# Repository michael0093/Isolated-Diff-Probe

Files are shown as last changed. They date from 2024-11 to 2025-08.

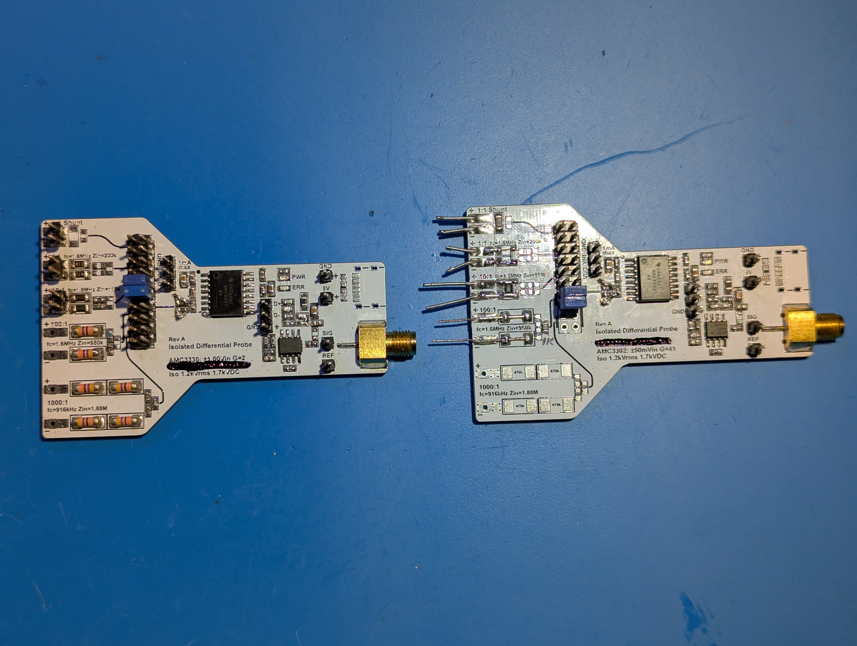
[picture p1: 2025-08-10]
Assembled front with rev A2 mods.jpg

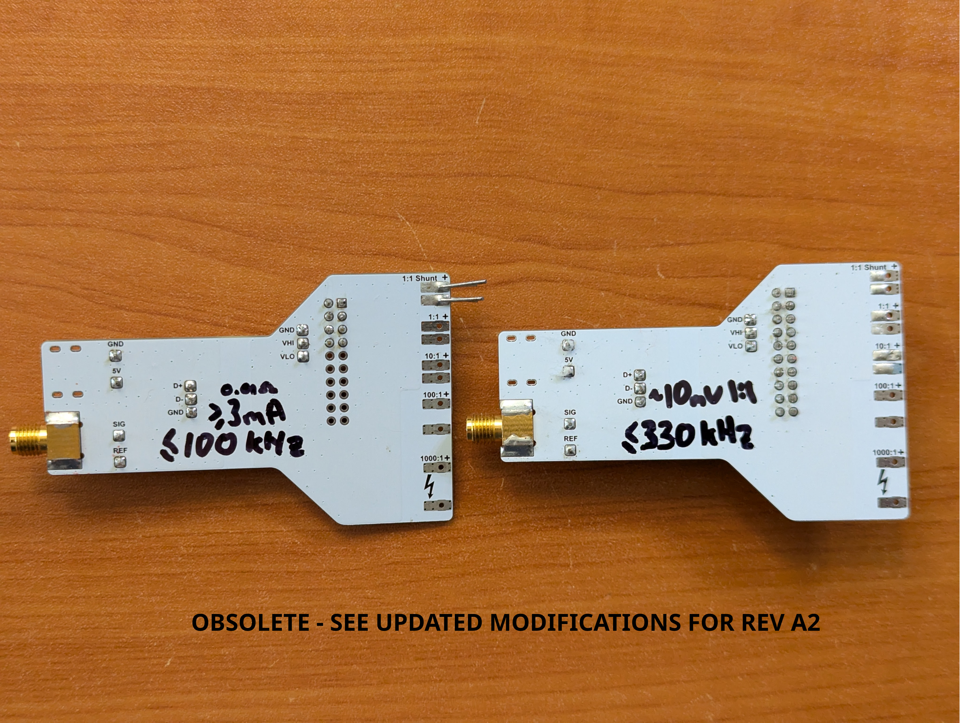
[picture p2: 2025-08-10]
Assembled back rev A1 mods.jpg

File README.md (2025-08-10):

# Overview
The Ti AMC33xx are differential isolated analog amplifiers rated for minimum 1.2kVrms insulation. The AMC3302 is intended for current shunt inputs as it has a +/-50mVpp input with a fixed gain of 41, whereas the AMC3330 is better for voltage measurements as it has a +/-1Vpp input and a fixed gain of 2. In these probes the AMC33xx do all the work, with their differential output converted to single-ended by a dual op-amp to better suit most oscilloscopes. 
By using two 2.54" jumpers on the 2x10 header, you can select between various input attenuators for low to high voltage use. 

# Design Notes
The power supply must be isolated from your scope as the scope "GND" of the SMA connector is a 50%VDD bias voltage. 
The schematic has two modifications from the rev A to rev A2 design - refer to the rev B schematic and follow the notes. The modifications are:
- Two biasing 1M (AMC3300) or 100k (AMC3302) resistors from near the input selector to HGND
- Two filtering 33pF (AMC3300) or 3.3nF (AMC3302) capacitors from near the input selector to HGND
- General note: The PCB is marked with an fc of the input circuit, not of the complete probe. The fc of the complete probe is about 300kHz.

The design was originally done in Altium and then converted to KiCad so appologies that the KiCad sch/pcb may not link up quite right. For that reason there are no propper rev B output files, and also note the rev B PCB still has outstanding changes as noted on the schematic.

Other opamps with GBWP >1MHz or so should perform similarly, the OPA2376 is just what was on hand.
Based on practical usage, the AMC3302 with a 0R01 shunt works best for currents >=3mA with fc=100kHz. The AMC3330 on 1:1 range works best for voltages >=10mV and fc=300kHz.

# Disclaimer
Only use the high voltage inputs if you are suitably qualified to measure lethal voltages and completely understand the risks. This project is provided as reference material only and anyone who attempts to make it must fully understand the risks and limitations of the isolator used - this project has absolutely no warranty and may be completely unsuitable for your use case. Use completely at your own risk!

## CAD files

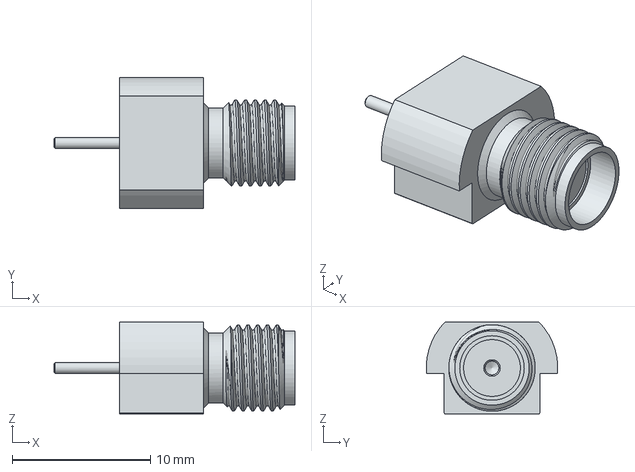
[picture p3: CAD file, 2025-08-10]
KiCad rev B/ALTIUM_EMBEDDED_MODELS/Cinch 142-0721-881.stp
17.4 x 9.52 x 6.65 mm

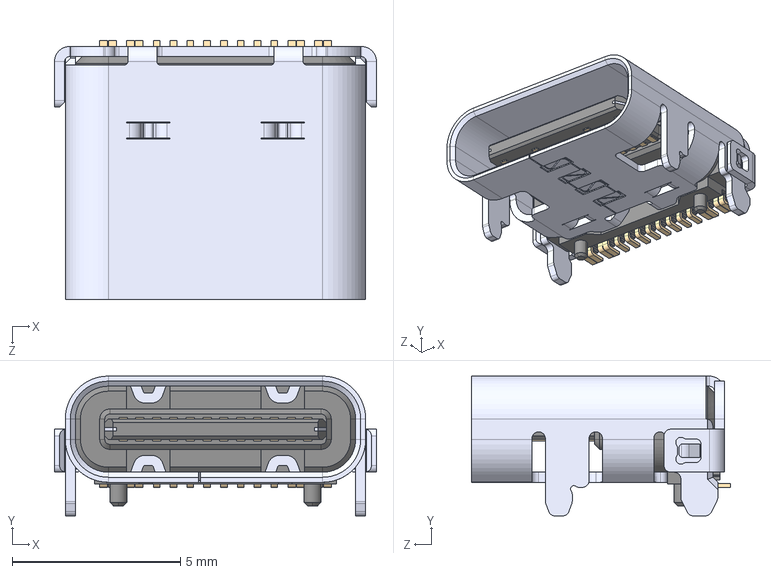
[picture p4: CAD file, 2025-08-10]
KiCad rev B/ALTIUM_EMBEDDED_MODELS/USB4105-GF-A--3DModel-STEP-46669.STEP
9.58 x 4.16 x 7.71 mm

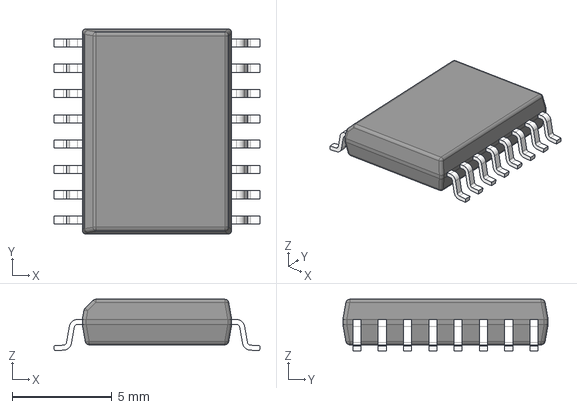
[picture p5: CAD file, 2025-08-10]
KiCad rev B/ALTIUM_EMBEDDED_MODELS/DW0016B.stp
10.3 x 10.3 x 2.59 mm
BODY-SOIC
LEAD-DW0016 x 16

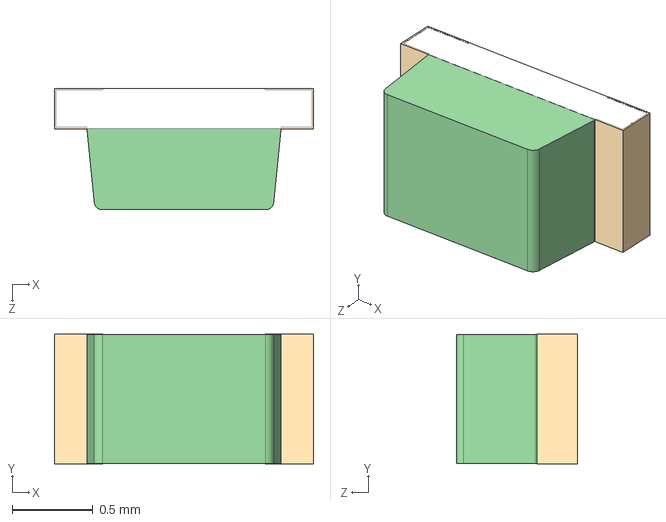
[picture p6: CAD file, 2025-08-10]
KiCad rev B/ALTIUM_EMBEDDED_MODELS/LED 0603 APT1608 GREEN.STEP
1.60 x 0.8 x 0.75 mm

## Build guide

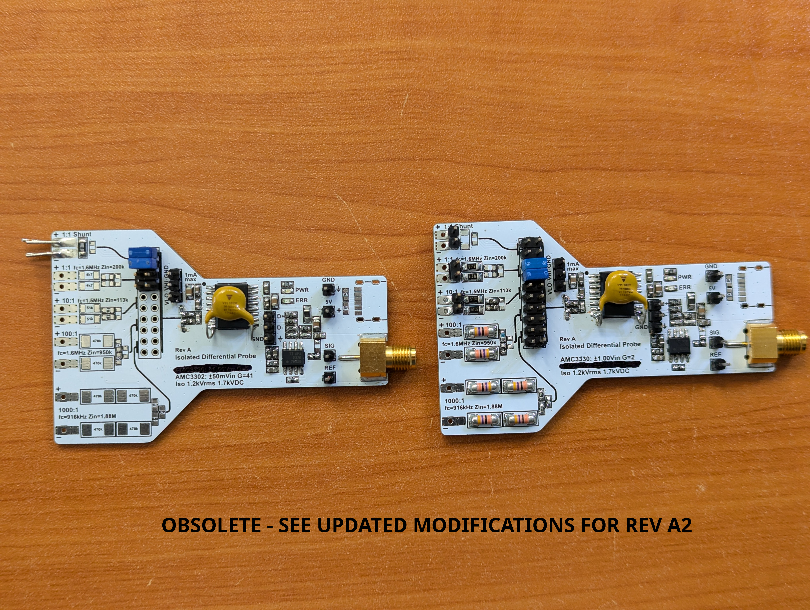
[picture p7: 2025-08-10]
Assembled front rev A1 mods.jpg

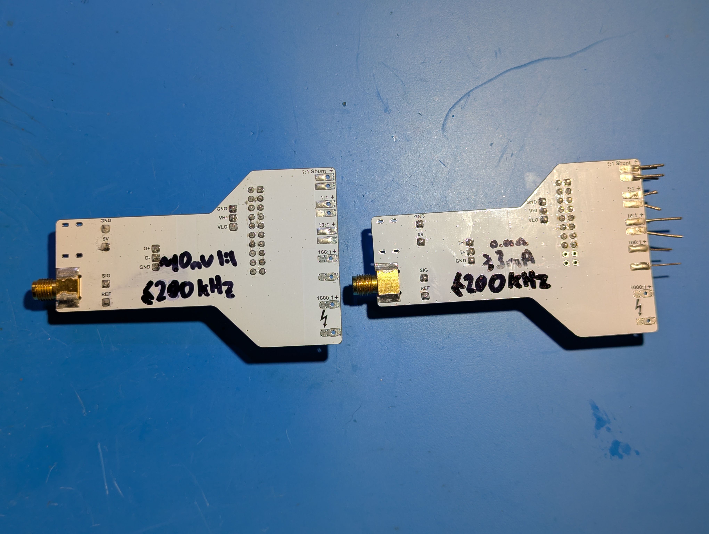
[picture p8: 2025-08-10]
Assembled back with rev A2 mods.jpg

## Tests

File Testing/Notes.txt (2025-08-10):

Changes to the rev A PCB to make rev A1:
 * 1nF Y1 capacitor between isolated GNDs avoids some weird noise 'glitches' at higher frequencies mainly on the AMC3302 (other values probably fine)
 * 1M bias resistors from each input to GND avoid clipping of tops of sine, probably due to bias
 * Adding 47uF HXD at input or output caps didn't help.
 * Opamp resistors change from 10k to 4k7 and the capacitors from 1nF to 100pF to increase frequency response
 * Actual opamp is OPA2376 (thats what was on hand)
 
At 5V input, typ current draw is 30mA

Shunt diff probe AMC3302:
 Fitted with 0R01 shunt LRMAM1206-R01FT5 (Element14 # 207-9442)
 Minimum recommended current with 10mR shunt = 3mA which results in about 1.2mV at output.
 Measured 3dB point (100mA on 0R01 shunt) = 220 kHz but see note below
 At higher freq the noise beats with the measurement so you get weirdness (note: adding 47uF or bigger Y1 doesnt help)
 Noise at output with shorted input much worse so dont do that (?)
 
Voltage diff probe AMC3330:
 470K on physical sample is the Resistor Today part
 Measured 3dB point (1Vpp input) = 330kHz
 The weirdness noted for AMC3302 is also present for AMC3330 if you have a small signal
    -- this root cause has been solved in rev B1 see below.

*******************************
Updates for Rev B August 2025: All of these except the diode and 1k shunt input resistors have been applied as mods for the rev A2 design

 * Change C12 and C15 to 33pF to improve frequency response
 * Updated input filter and bias, adding capacitance to HGND is what solves the "weirdness" observed before and negates the need for the Y1 cap. The Y1 cap is detremental to the higher voltage input options (waveform distortion)
   * For AMC3300 voltage probe, input filter/bias is: R34.R33=1M. C11,C20,C21=33pF. Added R35,R36 to reduce freq of shunt input (else >>1M target)
   * For AMC3302 current probe, input filter/bias is: R34.R33=100k. C11,C20,C21=3.3nF
 * Added anti-parallel diode at power input for crude polarity protection
 * For AMC3300 with shunt, added series R35,R36=1k and C1=100nF to reduce fc

Rev B1 AMC3302 measured frequency response with sine:
With 100pF in opamp circuit:
    large signal on 1R shunt:   4.76V at 1kHz --> 3.36V at 210kHz
    small signal on 0R01 shunt: 388mV at 1kHz --> 274mV at 230kHz
After changing to 33pF in opamp circuit: 1R shunt is about 280kHz -- see charts in folder.

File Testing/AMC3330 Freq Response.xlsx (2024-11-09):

Time | Milliseconds | Index | Freq | Vin | Vout | dB | Phase | Point of: | -3 | dB
2024-11-09 15:15 | 2008 | 0 | 100 | 0.3561504 | 0.347695 | -0.2086998211 | 1.8 | Is at: | 233957.04 | Hz
2024-11-09 15:15 | 3181 | 1 | 105 | 0.3493349 | 0.3419792 | -0.1848456719 | 1.875
2024-11-09 15:15 | 4342 | 2 | 110.25 | 0.3558902 | 0.3554921 | -0.009721504248 | 6
2024-11-09 15:15 | 5461 | 3 | 115.76 | 0.3554602 | 0.347701 | -0.1917008235 | 2.093023
2024-11-09 15:15 | 6561 | 4 | 121.55 | 0.3491731 | 0.341468 | -0.1938153554 | 2.195122
2024-11-09 15:15 | 7640 | 5 | 127.63 | 0.3544487 | 0.3550352 | 0.01436051032 | 6.923077
2024-11-09 15:15 | 8701 | 6 | 134.01 | 0.3522641 | 0.3451684 | -0.1767471226 | 2.432432
2024-11-09 15:16 | 9750 | 7 | 140.71 | 0.3498141 | 0.3427191 | -0.1779800397 | 7.605634
2024-11-09 15:16 | 10780 | 8 | 147.75 | 0.3535281 | 0.3467842 | -0.1672927404 | 2.647059
2024-11-09 15:16 | 11791 | 9 | 155.14 | 0.3481743 | 0.3412272 | -0.1750613728 | 2.8125
2024-11-09 15:16 | 12800 | 10 | 162.9 | 0.354125 | 0.3548377 | 0.01746336057 | 2.950819
2024-11-09 15:16 | 13782 | 11 | 171.05 | 0.3476241 | 0.3415127 | -0.1540603769 | 3.103448
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

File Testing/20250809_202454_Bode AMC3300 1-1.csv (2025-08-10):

Time | Milliseconds | Index | Freq | Vin | Vout | dB | Phase
2025-08-09 20:24:55.998415 | 1487 | 0 | 100 | 0.7121296 | 1.409242 | 5.928530805867616 | 1.8
2025-08-09 20:24:57.458087 | 2947 | 1 | 105.0 | 0.7028115 | 1.388614 | 5.914853606404074 | 1.894737
2025-08-09 20:24:58.895924 | 4385 | 2 | 110.25 | 0.7153466 | 1.41075 | 5.898670832471245 | 1.978022
2025-08-09 20:25:00.313034 | 5802 | 3 | 115.76 | 0.7137467 | 1.40952 | 5.910542585035337 | 2.068965
2025-08-09 20:25:01.726092 | 7215 | 4 | 121.55 | 0.7015346 | 1.384577 | 5.905360350617944 | 2.195122
2025-08-09 20:25:03.105063 | 8594 | 5 | 127.63 | 0.7138692 | 1.405347 | 5.883298525158161 | 2.278481
2025-08-09 20:25:04.465987 | 9955 | 6 | 134.01 | 0.7066419 | 1.394556 | 5.90473146793423 | 2.4
2025-08-09 20:25:05.809647 | 11299 | 7 | 140.71 | 0.7031512 | 1.38707 | 5.900993130069296 | 2.535211
2025-08-09 20:25:07.137218 | 12626 | 8 | 147.75 | 0.711116 | 1.402429 | 5.89880866777023 | 2.686567
2025-08-09 20:25:08.449217 | 13938 | 9 | 155.14 | 0.6994988 | 1.378212 | 5.890581063560397 | 2.8125
2025-08-09 20:25:09.754534 | 15244 | 10 | 162.9 | 0.7101219 | 1.399283 | 5.891453029734988 | 2.903226
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

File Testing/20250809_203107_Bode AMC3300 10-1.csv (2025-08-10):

Time | Milliseconds | Index | Freq | Vin | Vout | dB | Phase
2025-08-09 20:31:08.877084 | 1482 | 0 | 100 | 7.225853 | 1.401103 | -14.248381184582994 | -1.8
2025-08-09 20:31:10.336949 | 2942 | 1 | 105.0 | 7.123918 | 1.377365 | -14.27339737724514 | -1.894737
2025-08-09 20:31:11.780669 | 4386 | 2 | 110.25 | 7.259896 | 1.404466 | -14.26838338611185 | -1.978022
2025-08-09 20:31:13.198005 | 5803 | 3 | 115.76 | 7.244632 | 1.39961 | -14.280185861097717 | -2.093023
2025-08-09 20:31:14.595421 | 7200 | 4 | 121.55 | 7.123964 | 1.375184 | -14.287218107431585 | -2.195122
2025-08-09 20:31:15.975531 | 8581 | 5 | 127.63 | 7.249256 | 1.39523 | -14.312952617385342 | -2.307692
2025-08-09 20:31:17.336164 | 9941 | 6 | 134.01 | 7.176553 | 1.383823 | -14.296707039252043 | -2.4
2025-08-09 20:31:18.679773 | 11285 | 7 | 140.71 | 7.13756 | 1.375945 | -14.29897395304401 | -2.535211
2025-08-09 20:31:20.006949 | 12612 | 8 | 147.75 | 7.227983 | 1.392387 | -14.305143251901676 | -2.647059
2025-08-09 20:31:21.318870 | 13924 | 9 | 155.14 | 7.093113 | 1.364958 | -14.31435180723038 | -2.8125
2025-08-09 20:31:22.616050 | 15221 | 10 | 162.9 | 7.202491 | 1.389629 | -14.291677109993259 | -2.903226
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

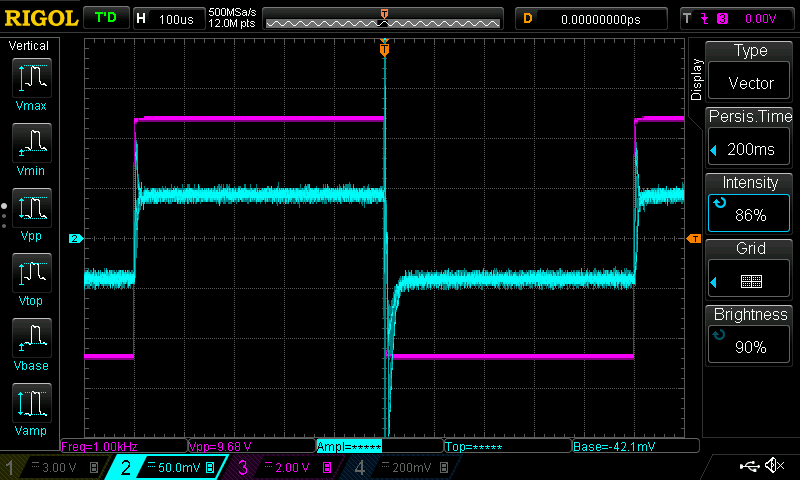
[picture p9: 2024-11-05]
Testing/AMC3302 100mA on 0R01 Square 1.png

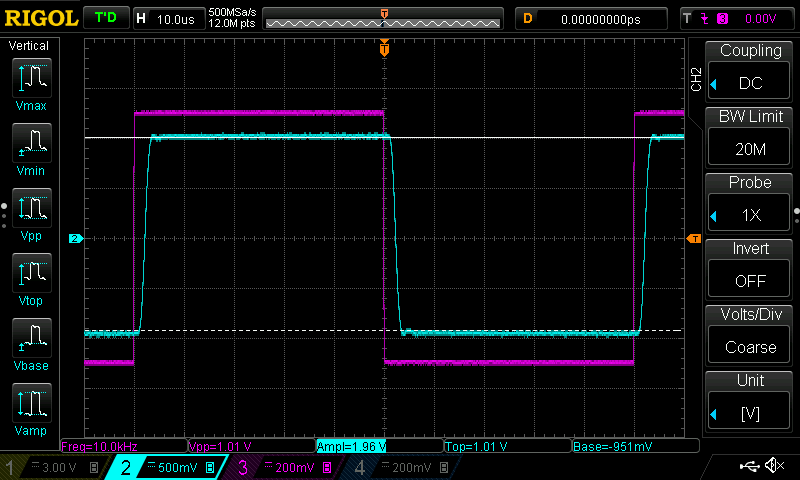
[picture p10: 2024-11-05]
Testing/AMC3330 1V 10kHz Square.png

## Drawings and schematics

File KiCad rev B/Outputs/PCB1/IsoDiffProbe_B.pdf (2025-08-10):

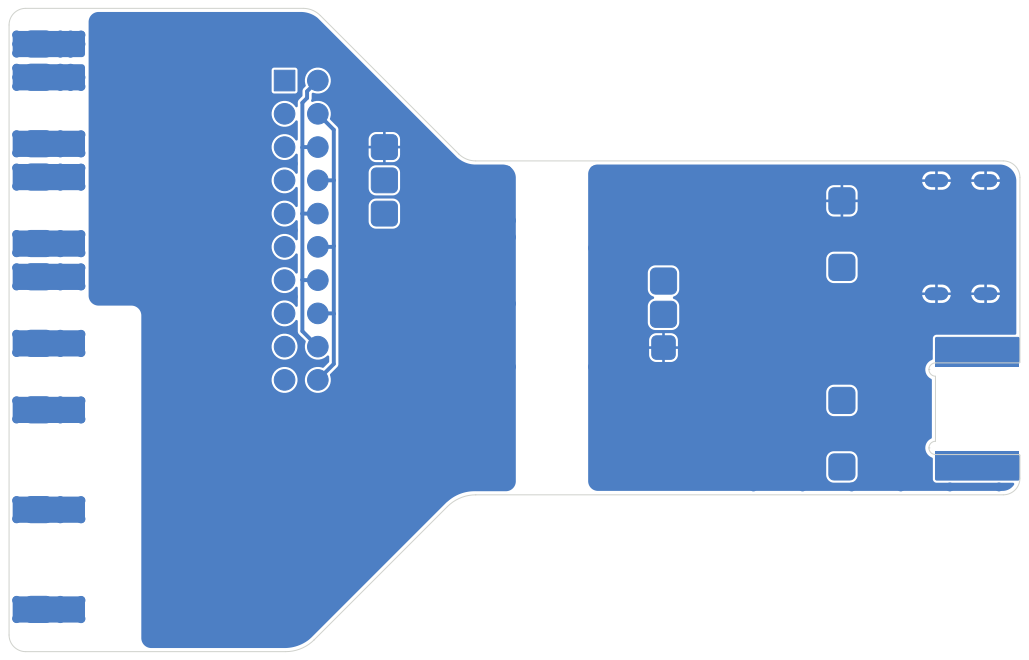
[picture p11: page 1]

Id: 1/5 Title: File: IsoDiffProbe_B.kicad_pcb Sheet:

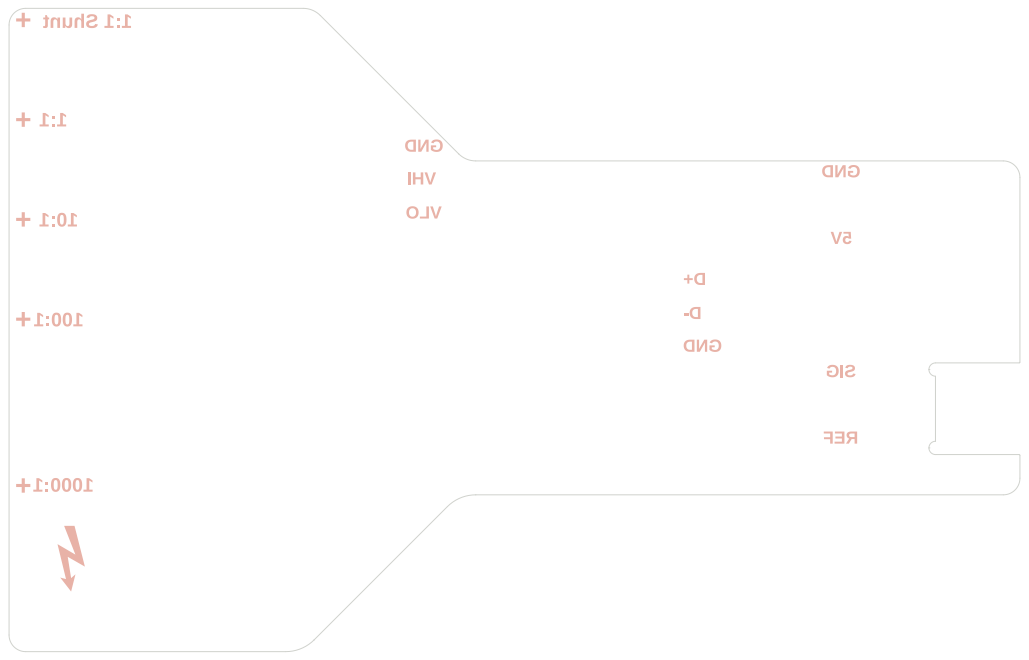
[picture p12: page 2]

Id: 2/5 Title: File: IsoDiffProbe_B.kicad_pcb Sheet:

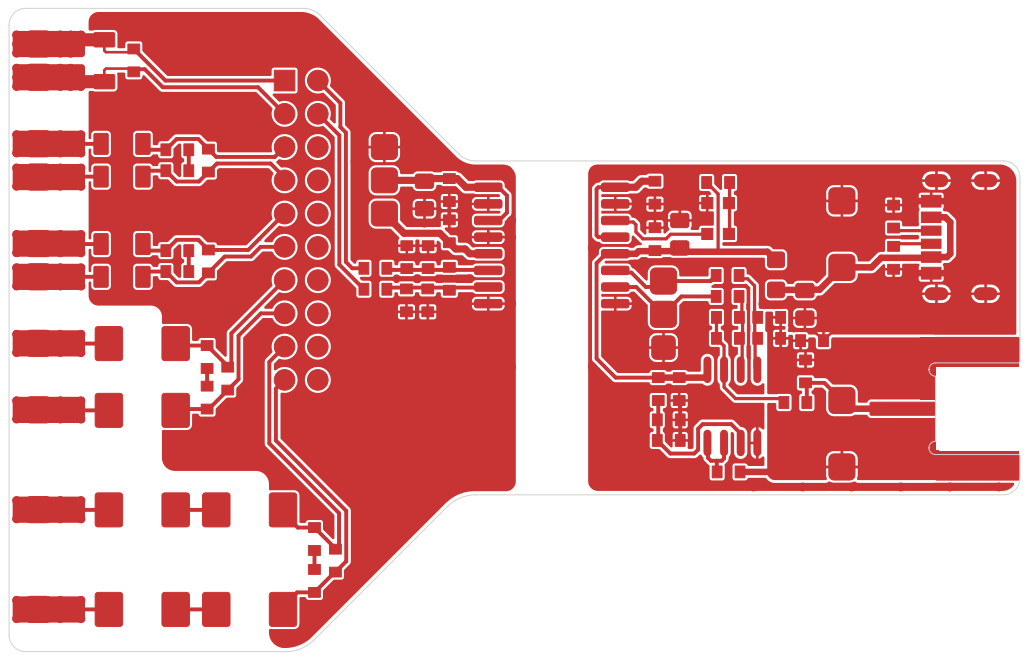
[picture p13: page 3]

Id: 3/5 Title: File: IsoDiffProbe_B.kicad_pcb Sheet:

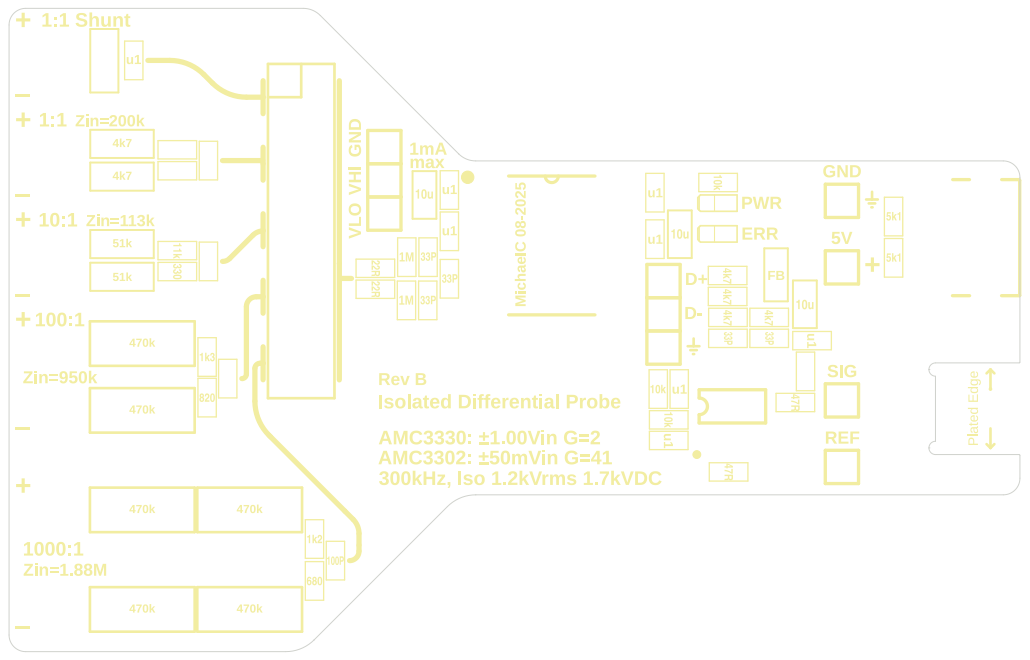
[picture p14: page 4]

Id: 4/5 Title: File: IsoDiffProbe_B.kicad_pcb Sheet:

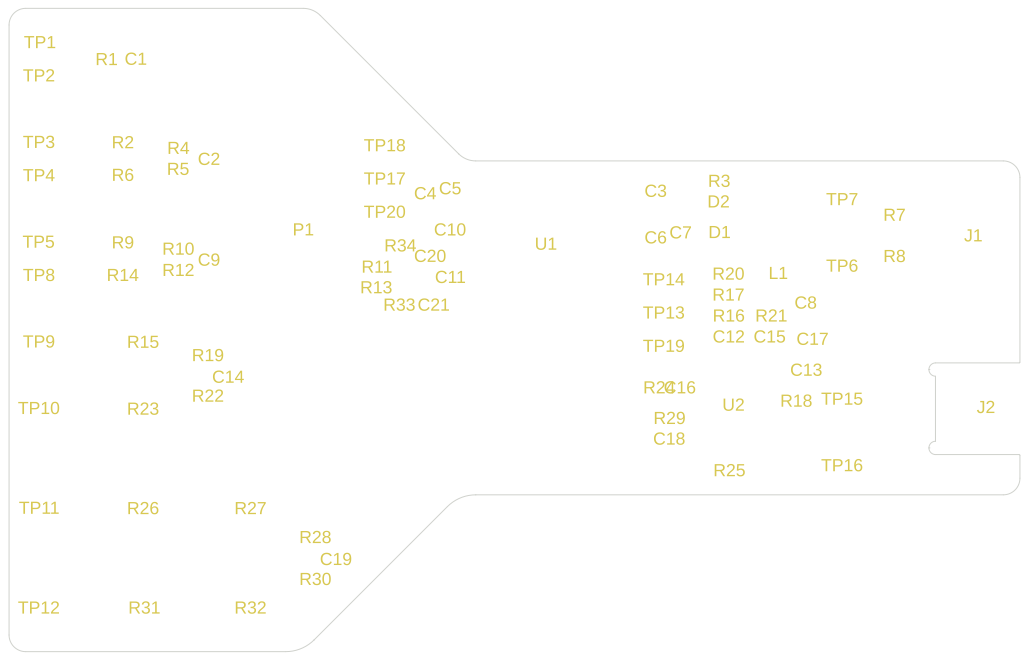
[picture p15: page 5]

Id: 5/5 Title: File: IsoDiffProbe_B.kicad_pcb Sheet:

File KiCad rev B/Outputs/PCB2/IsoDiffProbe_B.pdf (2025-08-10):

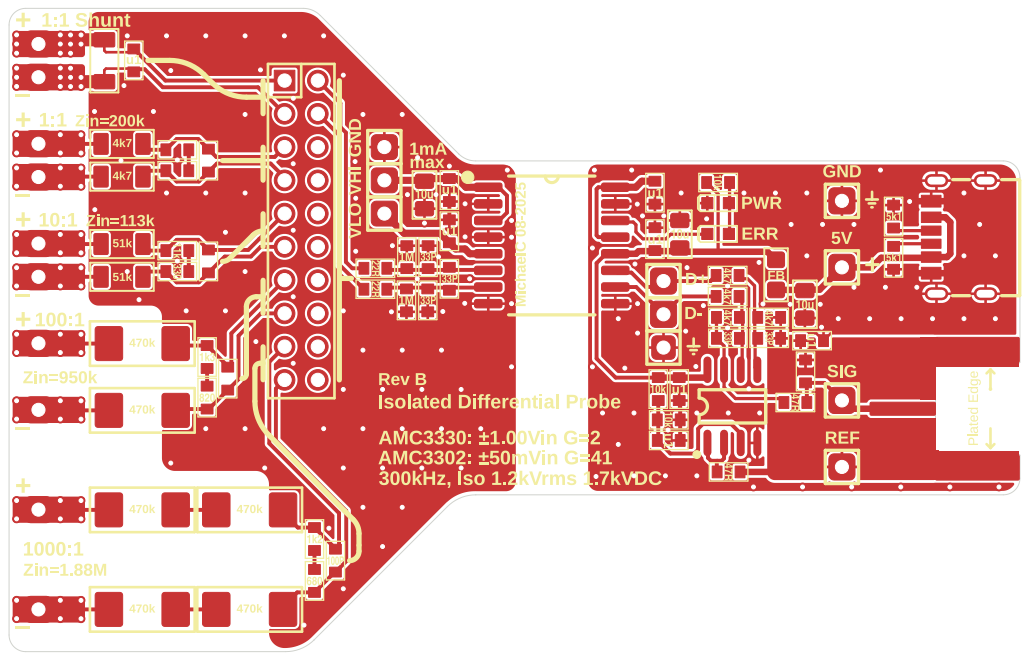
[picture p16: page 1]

Id: 1/1 Title: File: IsoDiffProbe_B.kicad_pcb Sheet:

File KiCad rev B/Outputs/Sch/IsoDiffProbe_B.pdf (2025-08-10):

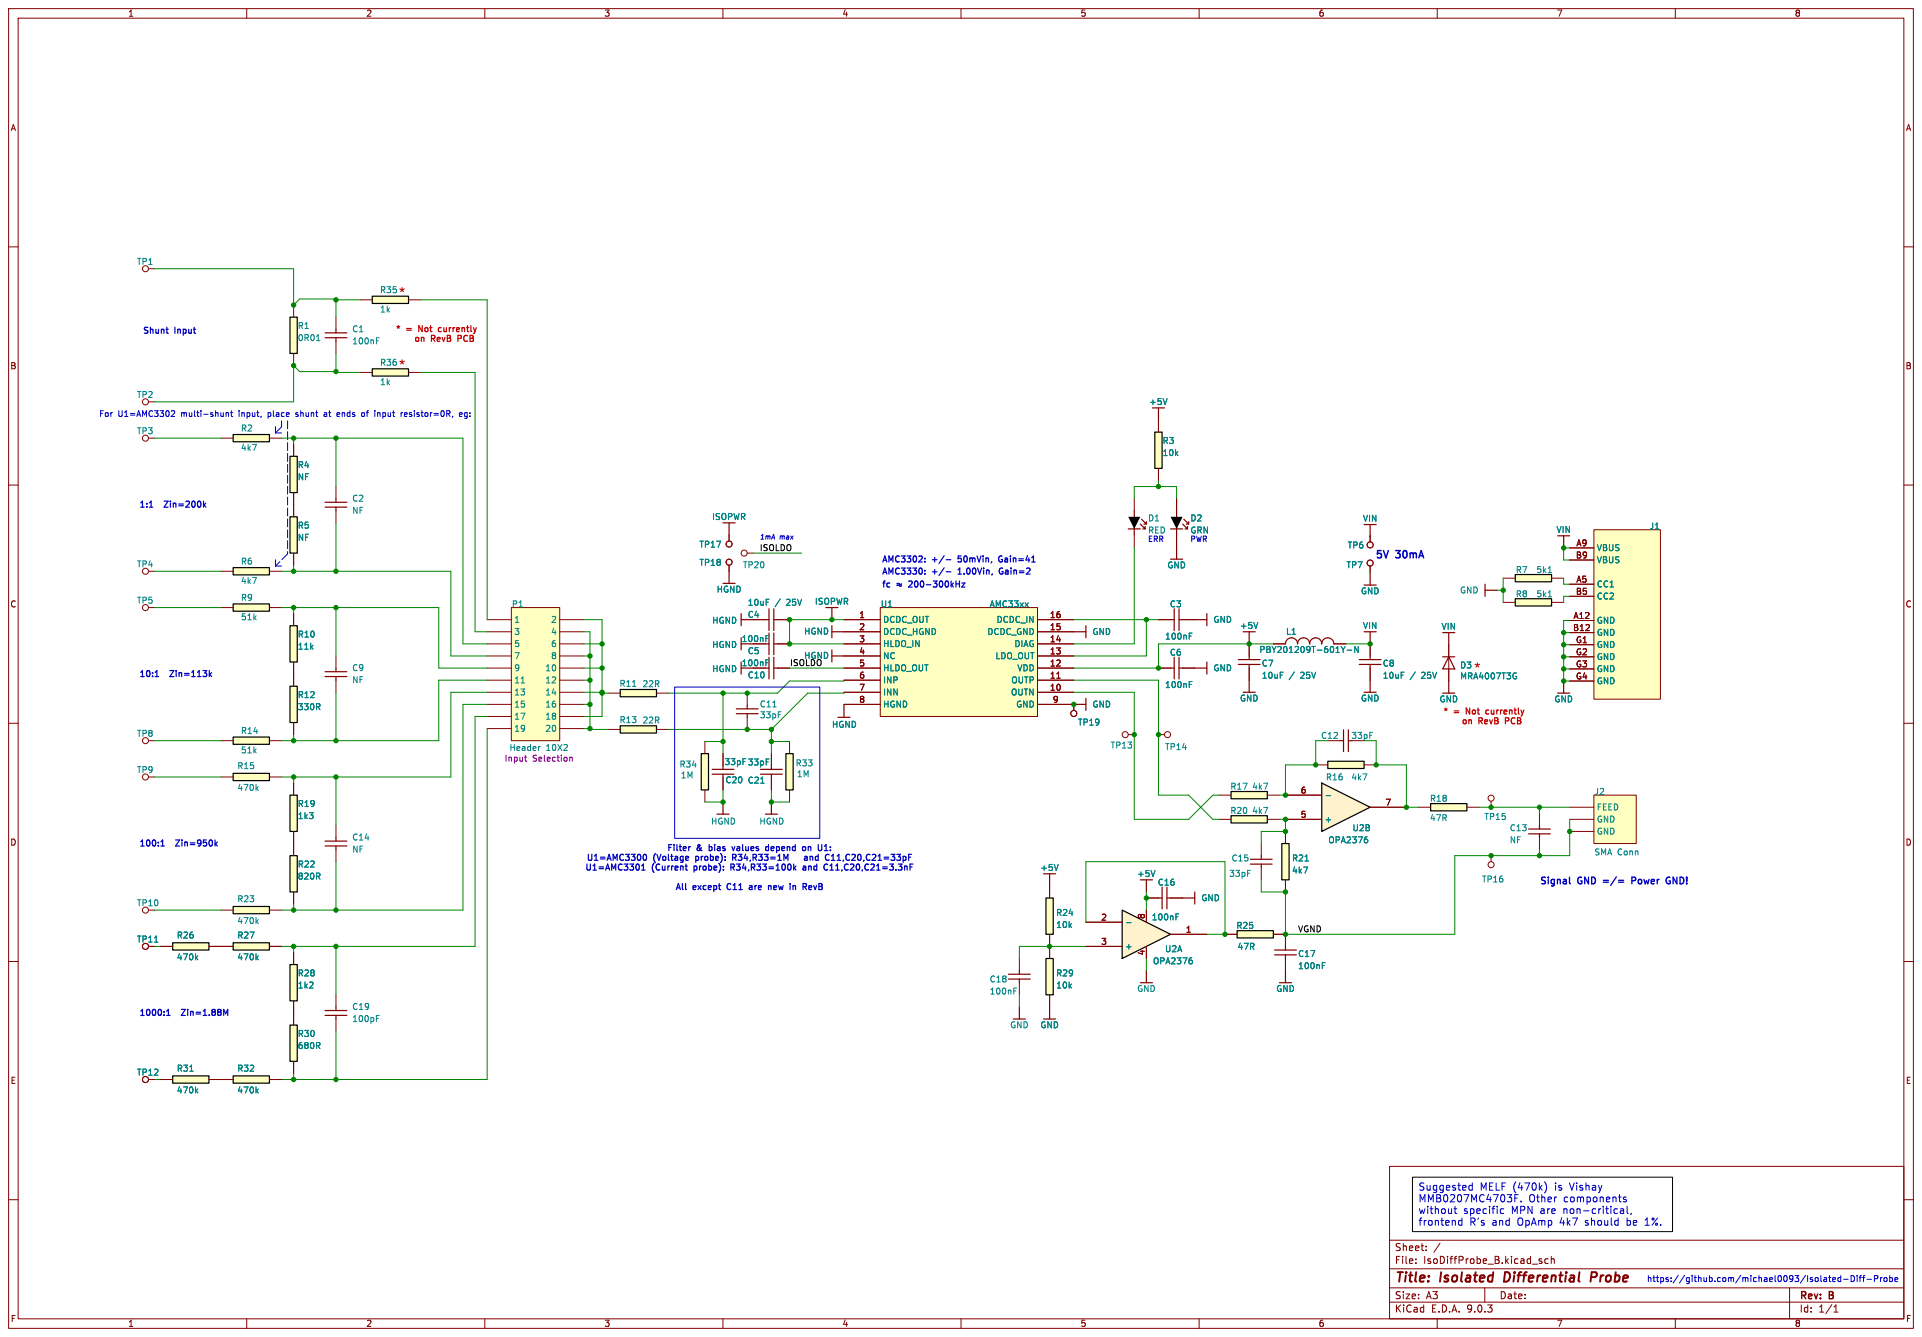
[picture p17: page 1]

* = Not currently on RevB PCB

https://github.com/michael0093/Isolated-Diff-Probe

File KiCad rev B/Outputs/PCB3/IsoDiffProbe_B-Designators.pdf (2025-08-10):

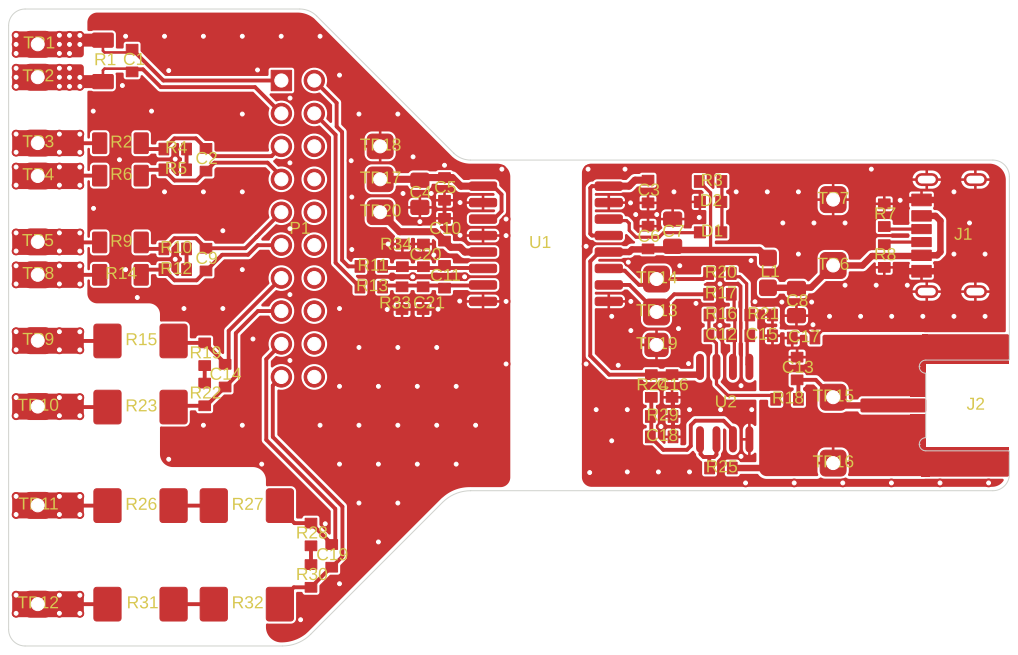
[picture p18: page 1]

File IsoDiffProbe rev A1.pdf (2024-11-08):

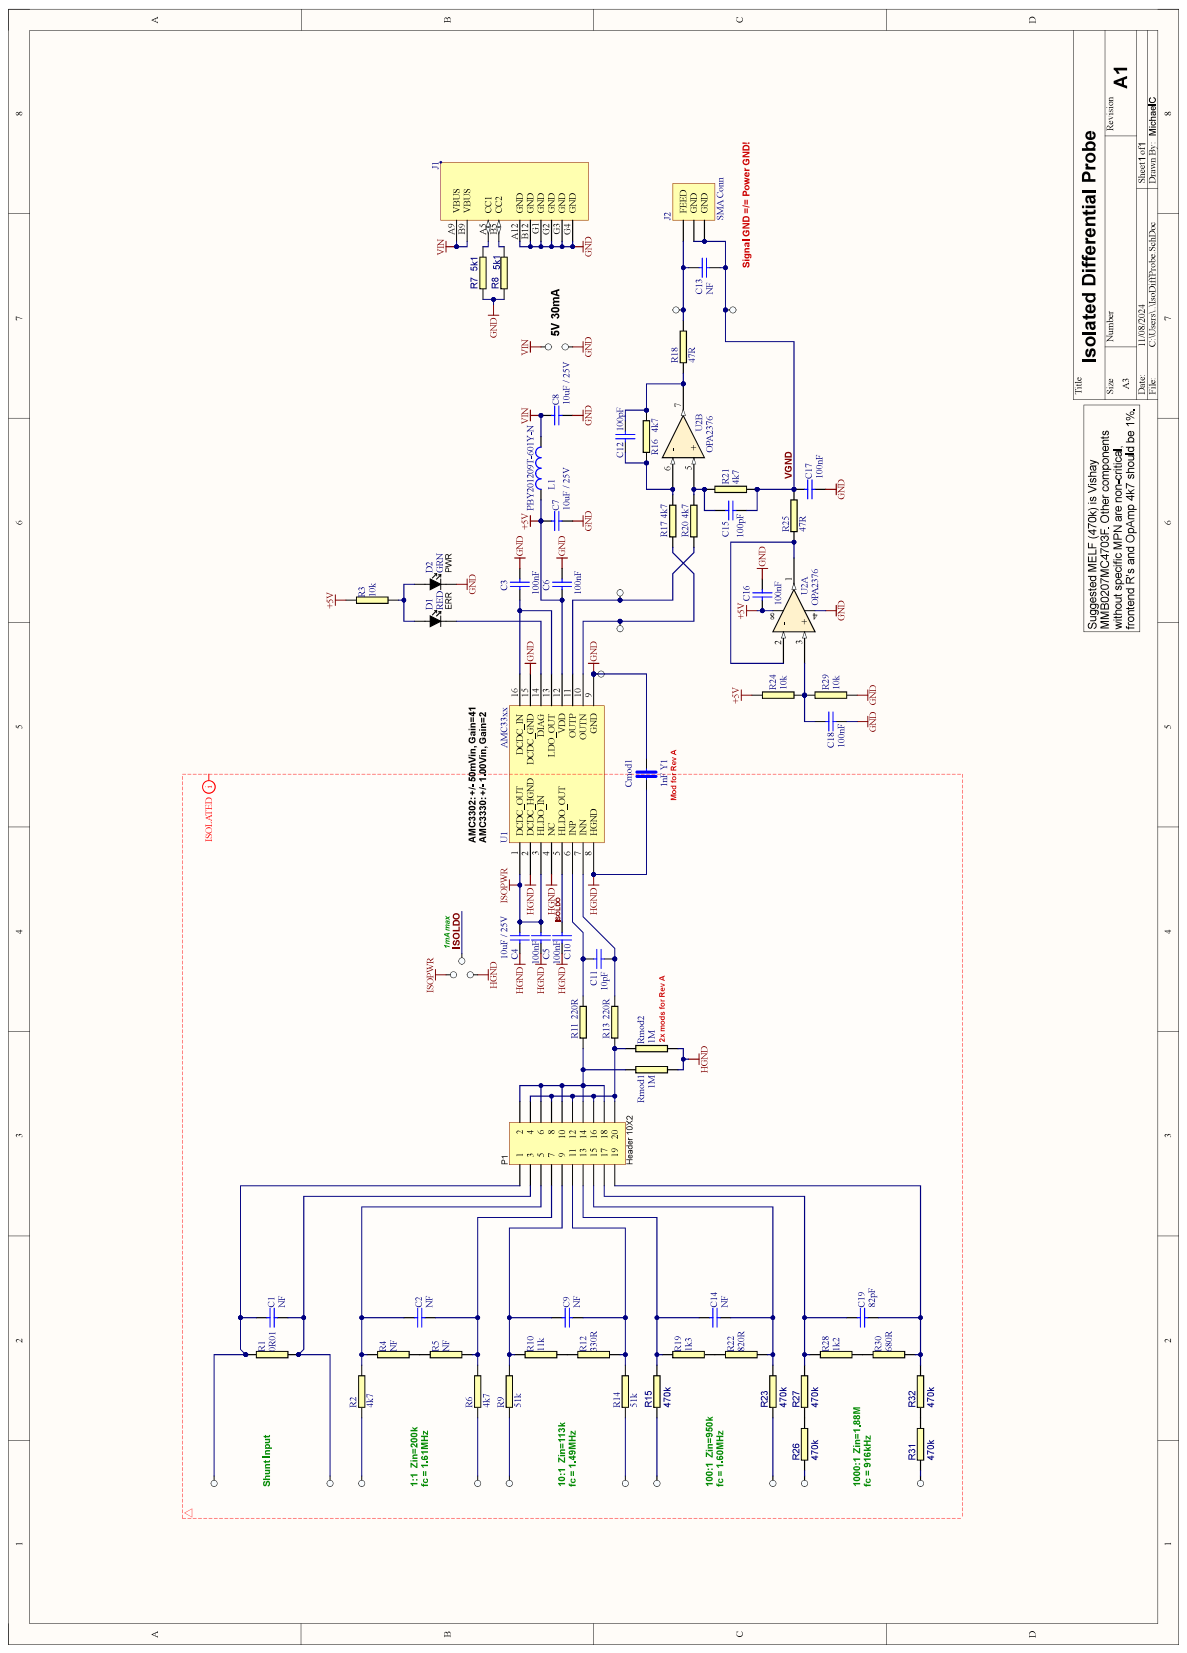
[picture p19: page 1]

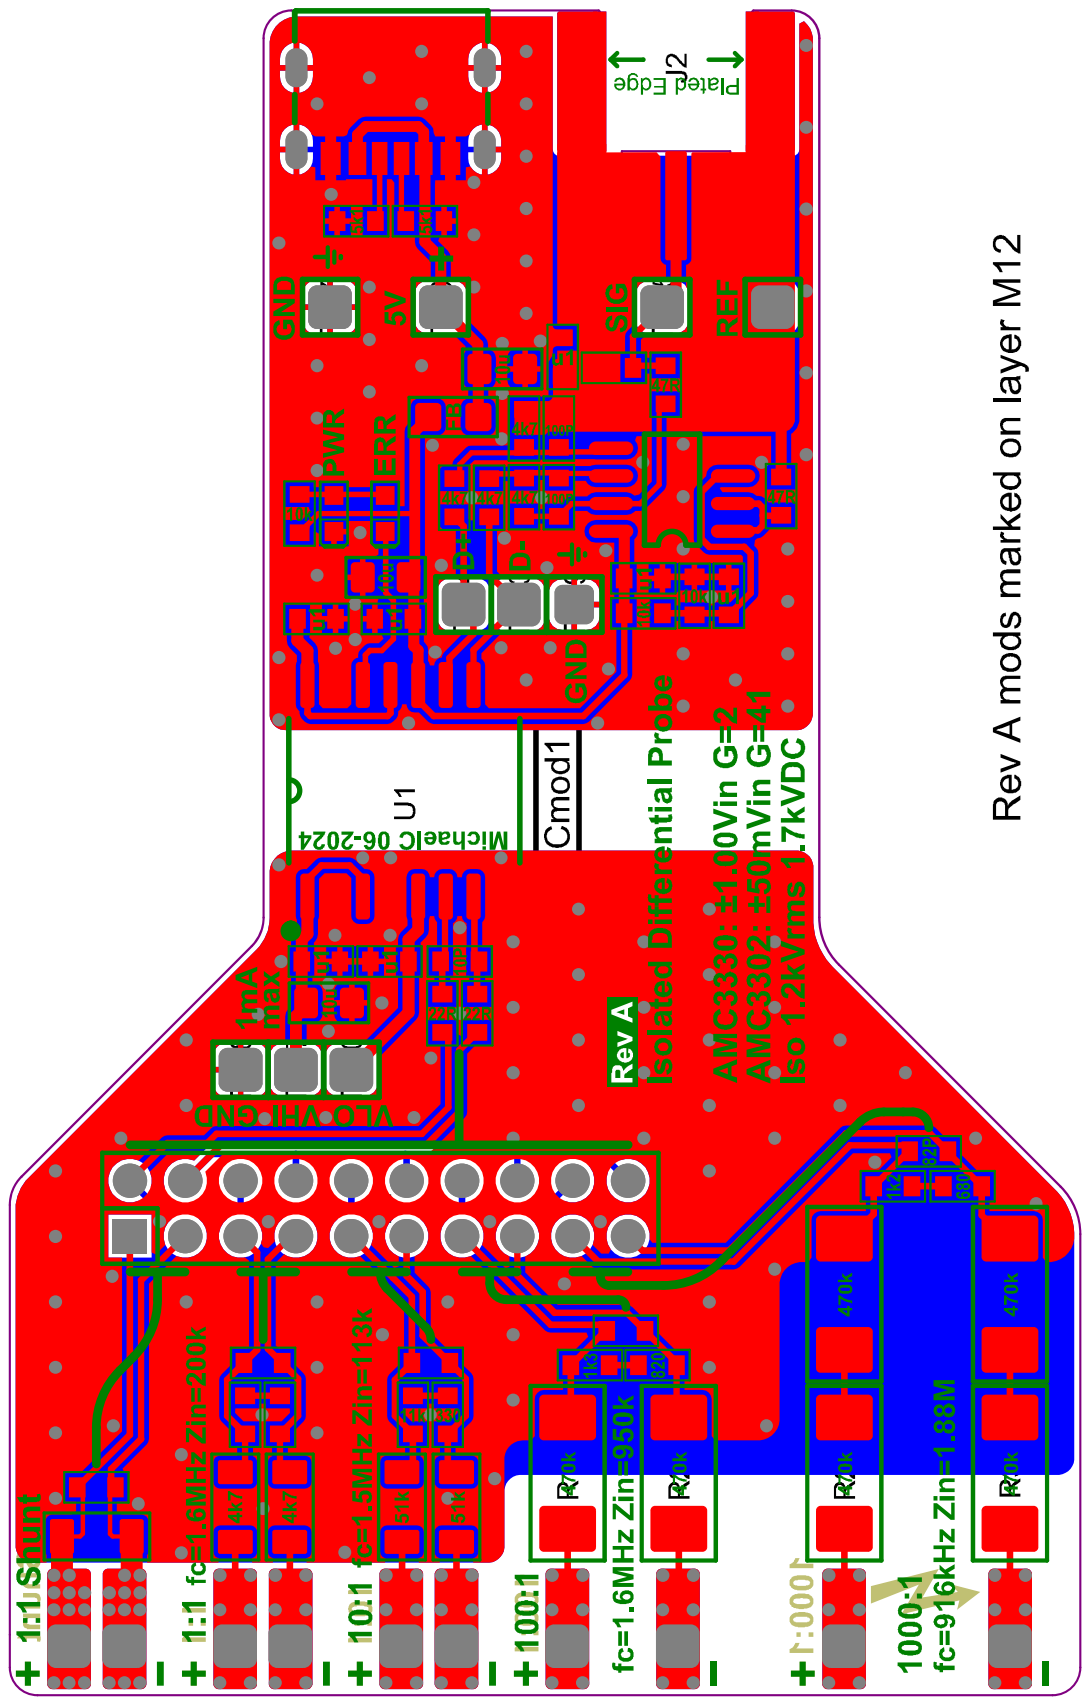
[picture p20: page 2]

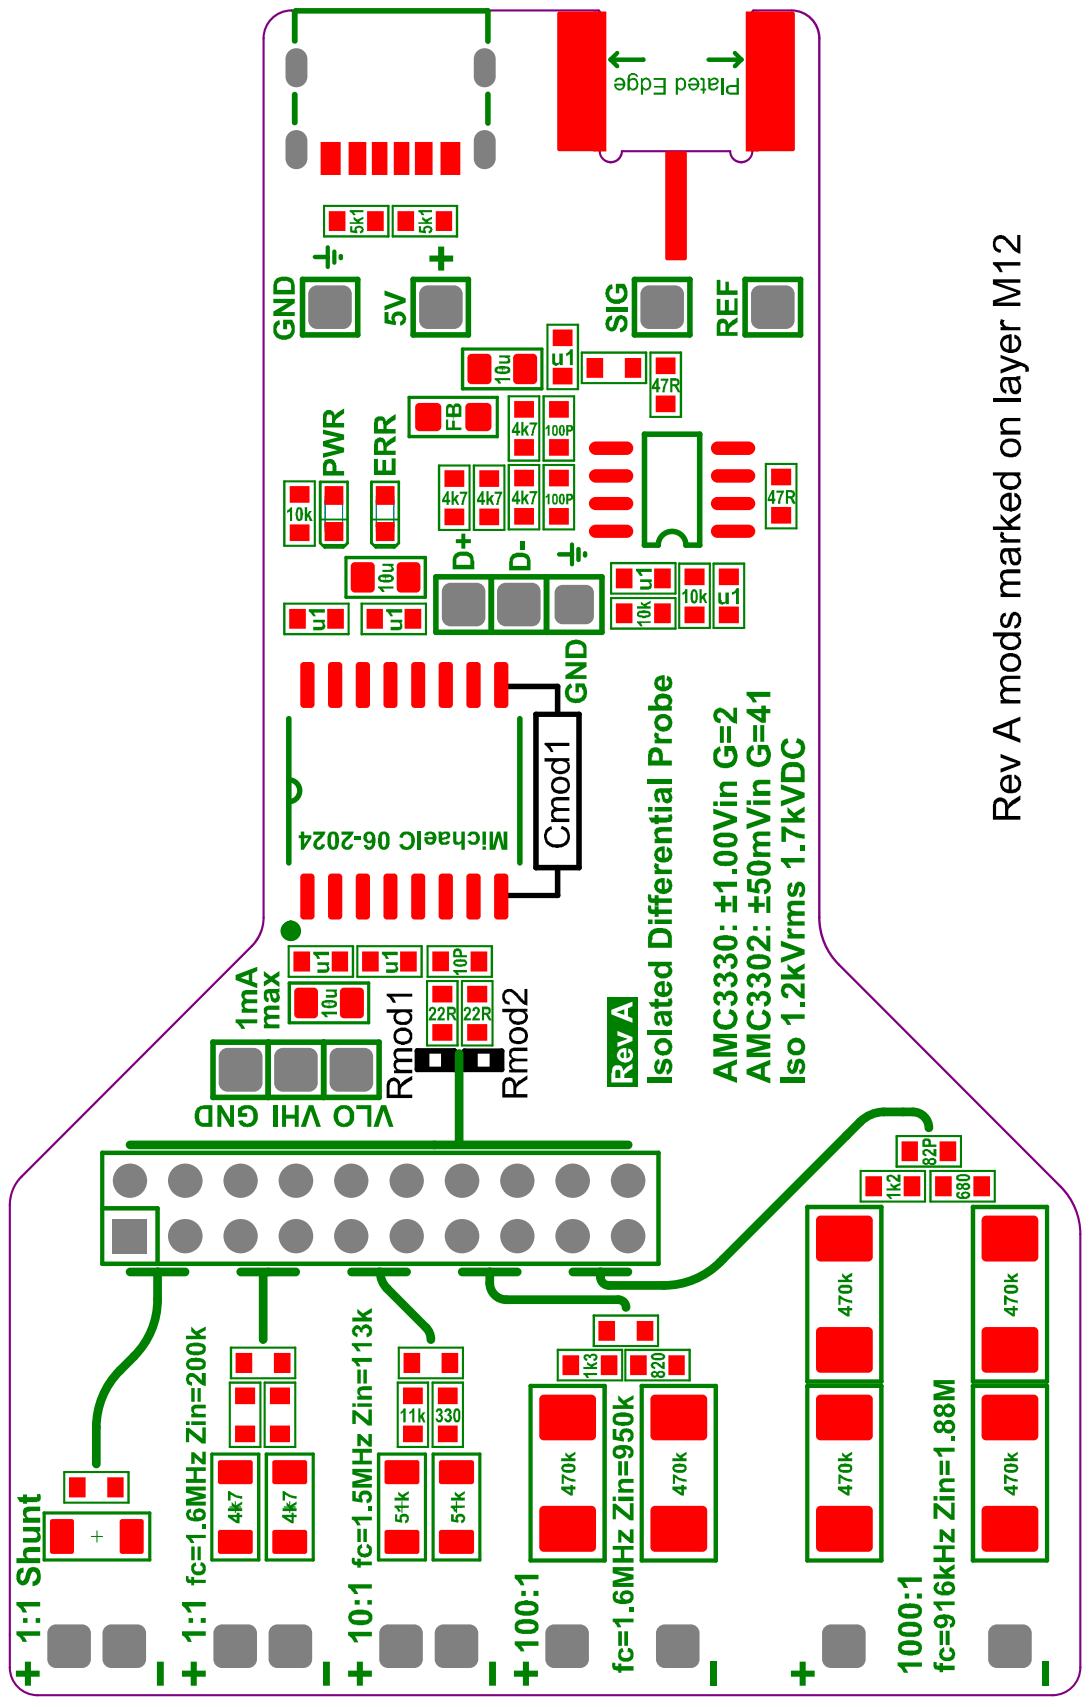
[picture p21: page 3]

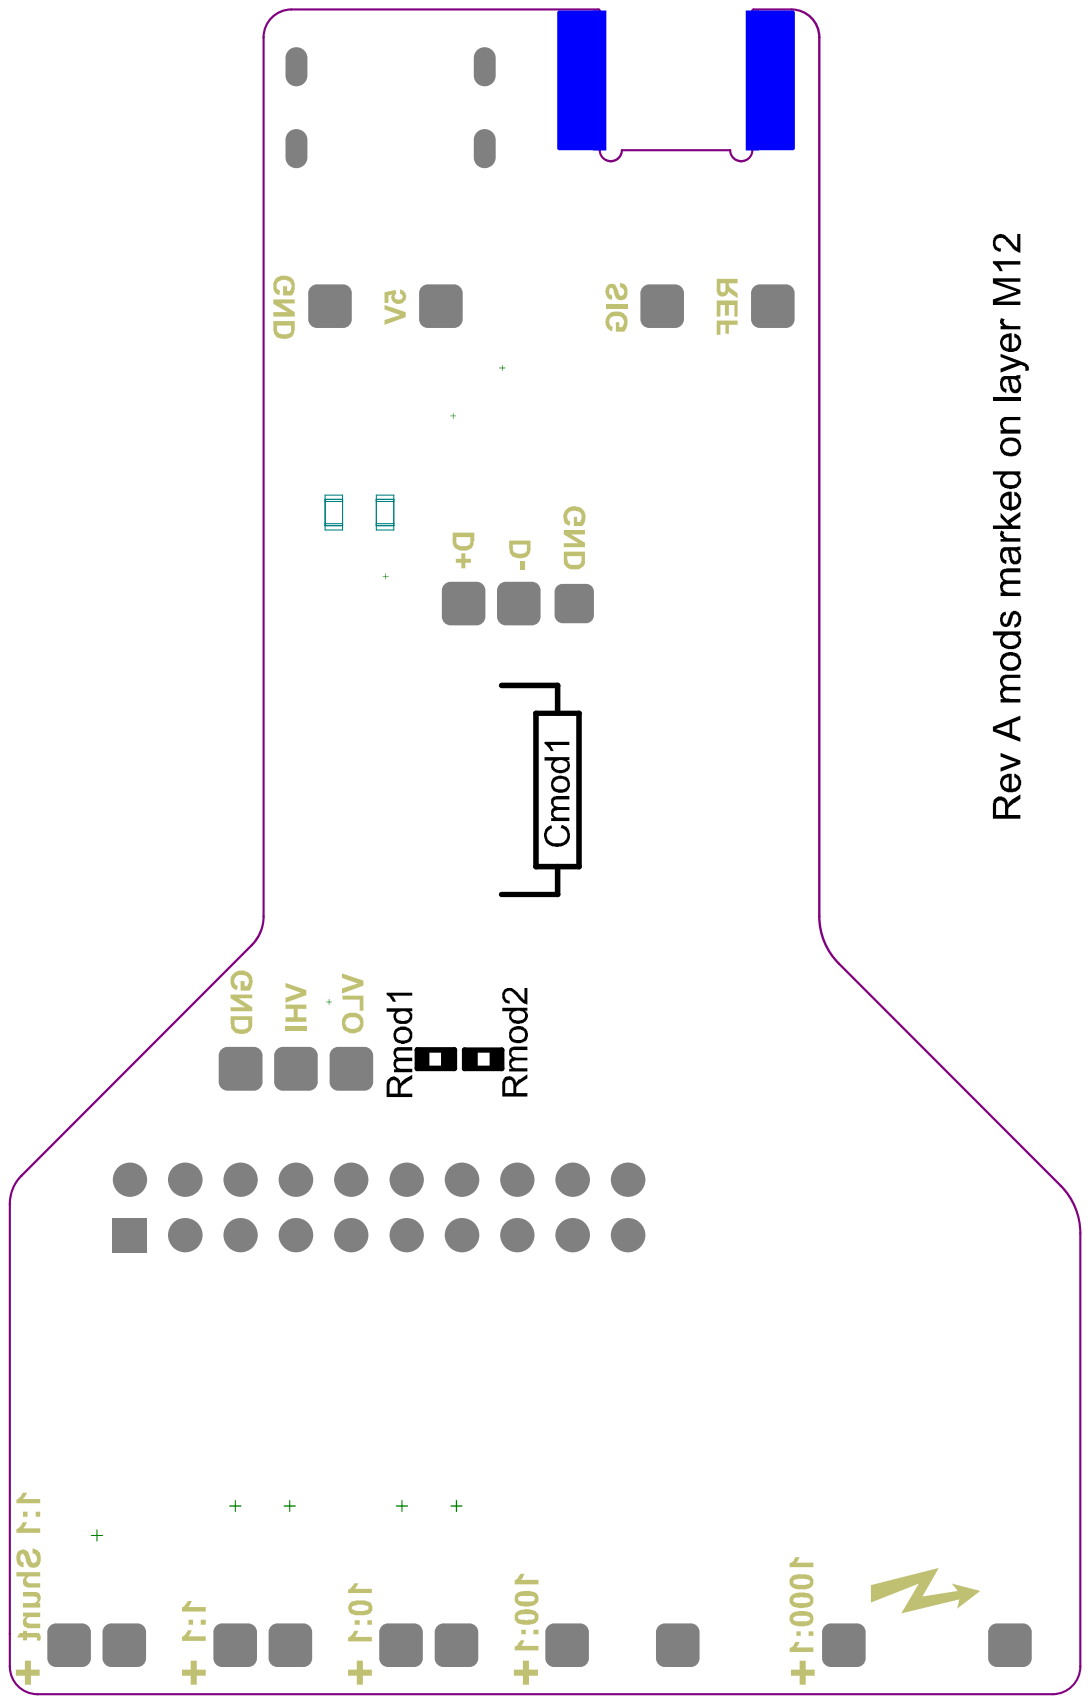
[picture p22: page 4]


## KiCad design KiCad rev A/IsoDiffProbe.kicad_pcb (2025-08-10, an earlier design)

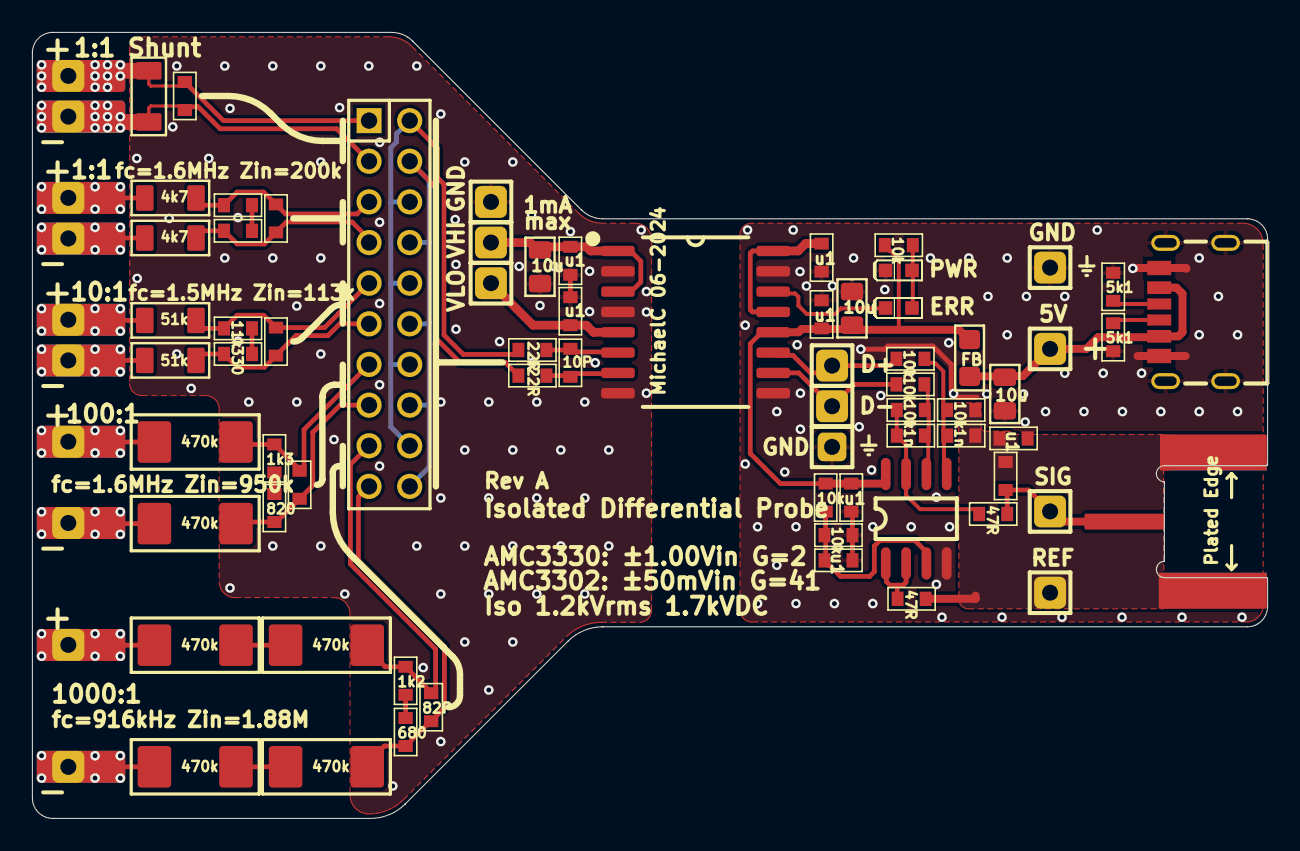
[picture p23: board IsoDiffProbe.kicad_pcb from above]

Board: 2 copper layers, 77.2 x 49.1 mm, 79 parts (0 on the bottom side), 48 nets.

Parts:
C1, C2, C9, C13, C14: NF; 0603
C3, C5, C6, C10, C16, C17, C18: 100nF; 0603
C4, C7, C8: 10uF / 25V; 0805_cap_Rounded
C11: 10pF; 0603
C12, C15: 1nF; 0603
C19: 82pF; 0603
D1: RED; LED-0603
D2: GRN; LED-0603
J1: USB C 6-Pin; USB-C_6pin_Conn
J2: SMA Conn; SMA_SMD
L1: PBY201209T-601Y-N; 0805_Rounded
P1: Header 10X2; IDC20
R1: 0R01; 1206
R2, R6: 4k7; 1206
R3, R16, R17, R20, R21, R24, R29: 10k; 0603
R4, R5: NF; 0603
R7, R8: 5k1; 0603
R9, R14: 51k; 1206
R10: 11k; 0603
R11, R13: 220R; 0603
R12: 330R; 0603
R15, R23, R26, R27, R31, R32: 470k; MMB0207
R18, R25: 47R; 0603
R19: 1k3; 0603
R22: 820R; 0603
R28: 1k2; 0603
R30: 680R; 0603
TP1, TP2, TP3, TP4, TP5, TP6, TP7, TP8, TP9, TP10, TP11, TP12, TP13, TP14, TP15, TP16, TP17, TP18, TP19, TP20: Test Point; TP
U1: AMC3; DW0016B
U2: TLC272ID; SO-8

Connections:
+5V: C6.2, C7.1, C16.1, L1.1, R3.2, R24.1, U1.12, U2.8
GND: C3.1, C6.1, C7.2, C8.2, C16.2, C17.2, C18.2, D2.K, J1.A12, J1.B12, J1.G1, J1.G2, J1.G3, J1.G4, R7.1, R8.1, R29.2, TP7.1, TP19.1, U1.9, U1.15, U2.4
HGND: C4.1, C5.2, C10.2, TP18.1, U1.2, U1.4, U1.8
ISOLDO: C10.1, TP20.1, U1.5
ISOPWR: C4.2, C5.1, TP17.1, U1.1, U1.3
NetC1_1: C1.1, P1.1, R1.2, TP1.1
NetC1_2: C1.2, P1.3, R1.1, TP2.1
NetC2_1: C2.1, P1.5, R2.2, R4.1
NetC2_2: C2.2, P1.7, R5.2, R6.2
NetC3_2: C3.2, U1.13, U1.16
NetC9_1: C9.1, P1.9, R9.2, R10.1
NetC9_2: C9.2, P1.11, R12.2, R14.2
NetC11_1: C11.1, R11.1, U1.6
NetC11_2: C11.2, R13.1, U1.7
NetC12_1: C12.1, R16.1, R17.1, U2.6
NetC12_2: C12.2, R16.2, R18.2, U2.7
NetC13_1: C13.1, J2.FEED, R18.1, TP15.1
NetC14_1: C14.1, P1.13, R15.2, R19.1
NetC14_2: C14.2, P1.15, R22.2, R23.2
NetC15_1: C15.1, R20.1, R21.1, U2.5
NetC18_1: C18.1, R24.2, R29.1, U2.3
NetC19_1: C19.1, P1.17, R27.2, R28.1
NetC19_2: C19.2, P1.19, R30.2, R32.2
NetD1_A: D1.A, D2.A, R3.1
NetD1_K: D1.K, U1.14
NetJ1_A5: J1.A5, R7.2
NetJ1_B5: J1.B5, R8.2
NetP1_2: P1.2, P1.6, P1.10, P1.14, P1.18, R11.2
NetP1_4: P1.4, P1.8, P1.12, P1.16, P1.20, R13.2
NetR2_1: R2.1, TP3.1
NetR4_2: R4.2, R5.1
NetR6_1: R6.1, TP4.1
NetR9_1: R9.1, TP5.1
NetR10_2: R10.2, R12.1
NetR14_1: R14.1, TP8.1
NetR15_1: R15.1, TP9.1
NetR17_2: R17.2, TP13.1, U1.10
NetR19_2: R19.2, R22.1
NetR20_2: R20.2, TP14.1, U1.11
NetR23_1: R23.1, TP10.1
NetR25_2: R25.2, U2.1, U2.2
NetR26_1: R26.1, TP11.1
NetR26_2: R26.2, R27.1
NetR28_2: R28.2, R30.1
NetR31_1: R31.1, TP12.1
NetR31_2: R31.2, R32.1
VGND: C13.2, C15.2, C17.1, J2.GND, R21.2, R25.1, TP16.1
VIN: C8.1, J1.A9, J1.B9, L1.2, TP6.1

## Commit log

2024-11-05 Tidy up and add rev A0 files from local copy
    [Cinch 142-0721-881.stp, DW0016B.stp, IsoDiffProbe.PcbDoc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]
2024-11-08 Clean Altium file. REv A1 mods
    [IsoDiffProbe.SchDoc, IsoDiffProbe.kicad_pcb, IsoDiffProbe.kicad_sch]
2024-11-09 Update readme and add bode plot
    [AMC3330 Freq Response.xlsx, Cinch 142-0721-881.stp, DW0016B.stp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]
2024-11-12 Add rev B PCB that includes mods (still not linked to sch)
    [Cinch 142-0721-881.stp, DW0016B.stp, IsoDiffProbe.kicad_pcb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]
2025-08-10 Value changes to improve rev A1->A2 and updated rev B design.
    [20250809_202454_Bode AMC3300 1-1.csv, 20250809_203107_Bode AMC3300 10-1.csv, 20250809_204619_Bode AMC3302 1R.csv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]
